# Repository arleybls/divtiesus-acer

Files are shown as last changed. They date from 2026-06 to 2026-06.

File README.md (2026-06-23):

# divtiesus-acer

A custom-PCB fork of **DivTIESUS** — a DivMMC-compatible SD/MMC card interface for the ZX Spectrum.

This fork is a **board re-layout only**: the CPLD firmware and its pinout are unchanged from
upstream, so the existing logic runs on the new PCB without modification.

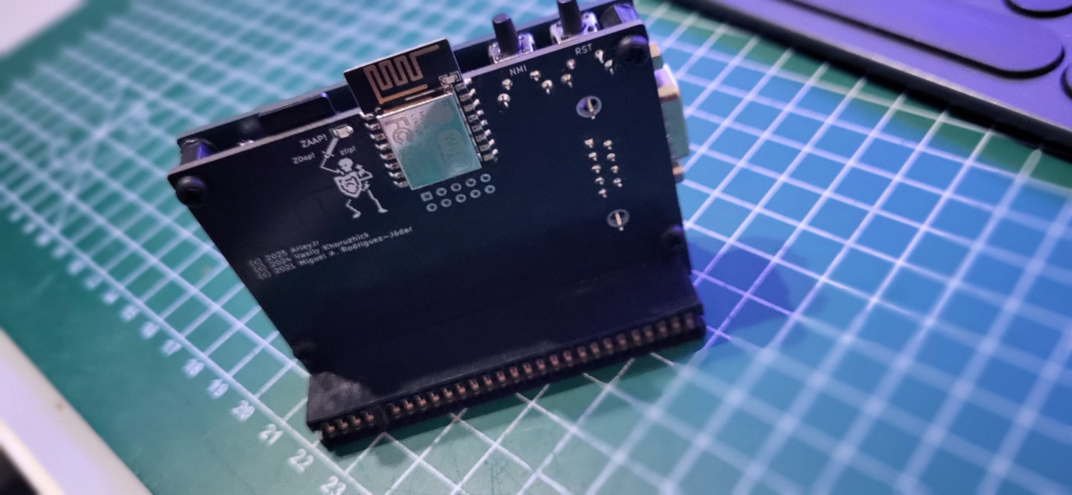
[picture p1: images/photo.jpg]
divtiesus-acer assembled board


## Lineage

| Stage | Author | Repo |
|---|---|---|
| Original DivTIESUS | Miguel Ángel Rodríguez Jodar (*mcleod-ideafix*) | https://github.com/mcleod-ideafix/divtiesus |
| KiCad redesign ("maple" edition) | anarsoul | https://github.com/anarsoul/divtiesus_maple |
| This fork (`divtiesus-acer`) | — | custom PCB re-layout based on the maple edition |

## What is unchanged from upstream

The entire `cpld/` directory matches the maple edition:

- Same Verilog sources: `tld_divtiesus.v`, `divmmc_mcleod.v`, `modo.v`, `segajoy.v`, `tres_e.v`,
  `uart.v`, `zxunoregs.v`, `zxunouart.v`
- Same `config.vh` and `Makefile`
- Same `tld_divtiesus.qsf` pin map — target device **Altera MAX II `EPM240T100C5`**

Inherited feature set:

- DivMMC-compatible interface with 8 KiB EEPROM and 128 KiB or 512 KiB RAM
- Automatic Spectrum model detection (no jumpers/switches)
- 24 MHz independent clock
- microSD card support with activity LED
- NMI and RESET buttons (file browser access)
- Optional ZX-Uno-compatible UART for WiFi (115200 baud)
- Kempston joystick interface (Atari and Sega controllers)
- Soft +3E feature removed (as in the maple edition)

## License

GPLv3, inherited from the upstream sources (see the GPL headers in `cpld/tld_divtiesus.v` and the
ZX-Uno notice in `cpld/config.vh`).

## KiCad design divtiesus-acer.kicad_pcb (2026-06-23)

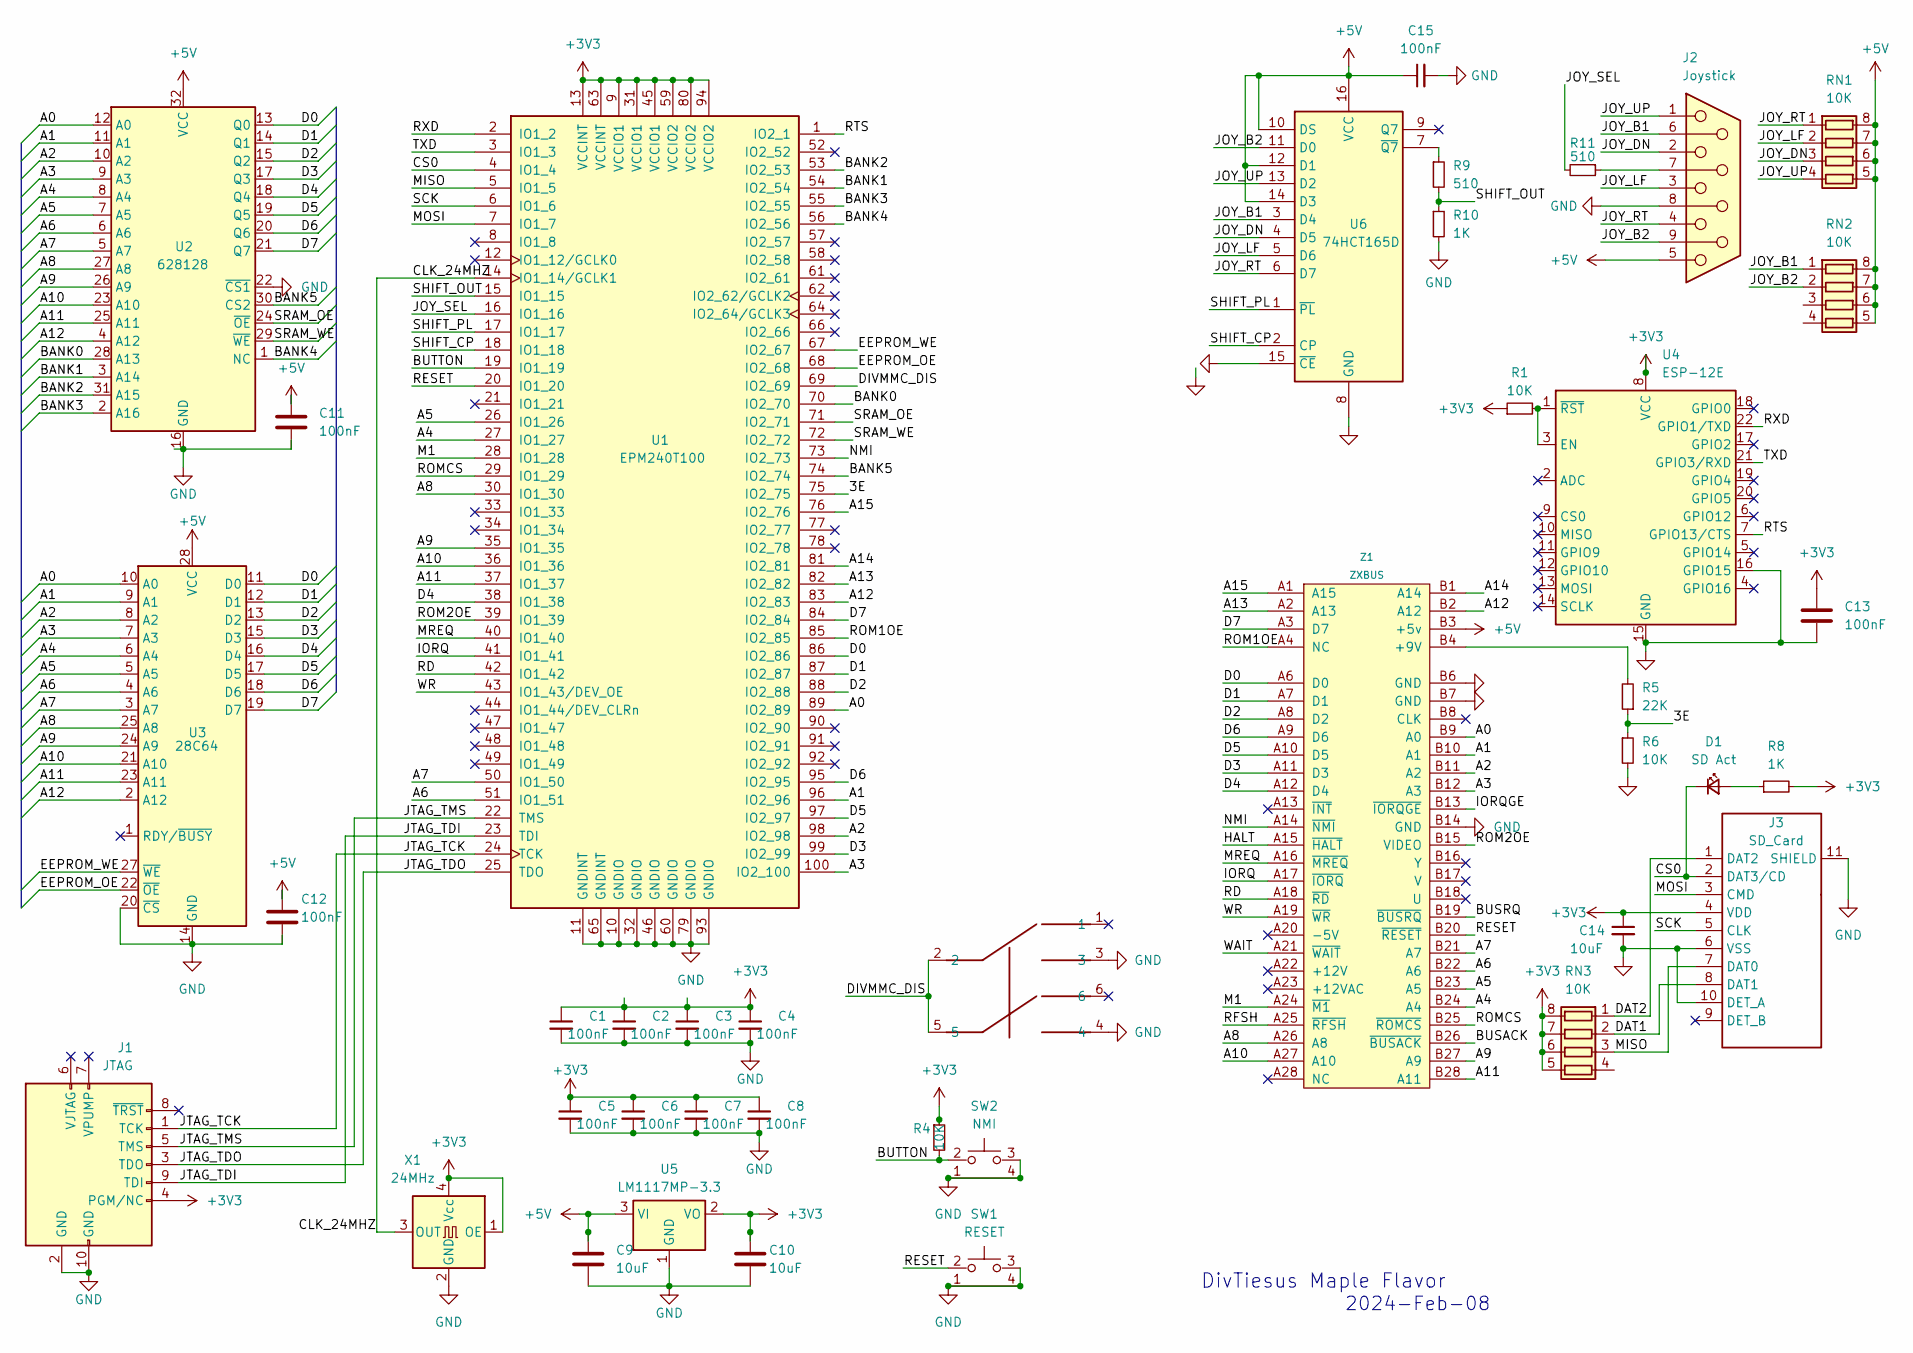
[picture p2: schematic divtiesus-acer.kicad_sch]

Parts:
C1, C2, C3, C4, C5, C6, C7, C8, C11, C12, C13, C15: 100nF; C_0603_1608Metric
C9, C10, C14: 10uF; C_0805_2012Metric
D1: SD Act; LED_0805_2012Metric
J1: JTAG; IDC-Header_2x05_P2.54mm_Vertical
J2: Joystick; DSUB-9_Male_Horizontal_P2.77x2.84mm_EdgePinOffset9.90mm_Hou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
J3: SD_Card; microSD_HC_Hirose_DM3D-SF; PARTREV AX6
JUMPER_E2: SWITCH_SMD_6PIN; SWICTH_SMD_6P
R1, R4, R6: 10K; R_0603_1608Metric
R5: 22K; R_0603_1608Metric
R8, R10: 1K; R_0603_1608Metric
R9, R11: 510; R_0603_1608Metric
RN1, RN2, RN3: 10K; R_Array_Convex_4x0603
SW1: RESET; SW_Tactile_SPST_Angled_PTS645Vx58-2LFS
SW2: NMI; SW_Tactile_SPST_Angled_PTS645Vx58-2LFS
U1: EPM240T100; TQFP-100_14x14mm_P0.5mm
U2: 628128; SSOP-32_11.305x20.495mm_P1.27mm
U3: 28C64; SOIC-28W_7.5x17.9mm_P1.27mm
U4: ESP-12E
U5: LM1117MP-3.3; SOT-223-3_TabPin2
U6: 74HCT165D; SOIC-16_3.9x9.9mm_P1.27mm
X1: 24MHz; Oscillator_SMD_SeikoEpson_SG8002CE-4Pin_3.2x2.5mm
Z1: ZXBUS; CONECTOR_SIMPLE_CARA

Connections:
+3V3: C1.1, C2.1, C3.1, C4.1, C5.1, C6.1, C7.1, C8.1, C10.1, C13.1, C14.1, J1.4 (PGM/NC), J3.4 (VDD), R1.1, R4.1, R8.2, RN3.5 (R4.2), RN3.6 (R3.2), RN3.7 (R2.2), RN3.8 (R1.2), U1.9 (VCCIO1), U1.13 (VCCINT), U1.31 (VCCIO1), U1.45 (VCCIO1), U1.59 (VCCIO2), U1.63 (VCCINT), U1.80 (VCCIO2), U1.94 (VCCIO2), U4.8 (VCC), U5.2 (VO), X1.1 (OE), X1.4 (Vcc)
+5V: C9.1, C11.1, C12.1, C15.1, J2.5, RN1.5 (R4.2), RN1.6 (R3.2), RN1.7 (R2.2), RN1.8 (R1.2), RN2.5 (R4.2), RN2.6 (R3.2), RN2.7 (R2.2), RN2.8 (R1.2), U2.32 (VCC), U3.28 (VCC), U5.3 (VI), U6.10 (DS), U6.12 (D1), U6.14 (D3), U6.16 (VCC), Z1.B3 (+5v)
/3E: R5.1, R6.1, U1.75 (IO2_75)
/A0: U1.89 (IO2_89), U2.12 (A0), U3.10 (A0), Z1.B9 (A0)
/A1: U1.96 (IO2_96), U2.11 (A1), U3.9 (A1), Z1.B10 (A1)
/A2: U1.98 (IO2_98), U2.10 (A2), U3.8 (A2), Z1.B11 (A2)
/A3: U1.100 (IO2_100), U2.9 (A3), U3.7 (A3), Z1.B12 (A3)
/A4: U1.27 (IO1_27), U2.8 (A4), U3.6 (A4), Z1.B24 (A4)
/A5: U1.26 (IO1_26), U2.7 (A5), U3.5 (A5), Z1.B23 (A5)
/A6: U1.51 (IO1_51), U2.6 (A6), U3.4 (A6), Z1.B22 (A6)
/A7: U1.50 (IO1_50), U2.5 (A7), U3.3 (A7), Z1.B21 (A7)
/A8: U1.30 (IO1_30), U2.27 (A8), U3.25 (A8), Z1.A26 (A8)
/A9: U1.35 (IO1_35), U2.26 (A9), U3.24 (A9), Z1.B27 (A9)
/A10: U1.36 (IO1_36), U2.23 (A10), U3.21 (A10), Z1.A27 (A10)
/A11: U1.37 (IO1_37), U2.25 (A11), U3.23 (A11), Z1.B28 (A11)
/A12: U1.83 (IO2_83), U2.4 (A12), U3.2 (A12), Z1.B2 (A12)
/A13: U1.82 (IO2_82), Z1.A2 (A13)
/A14: U1.81 (IO2_81), Z1.B1 (A14)
/A15: U1.76 (IO2_76), Z1.A1 (A15)
/BANK0: U1.70 (IO2_70), U2.28 (A13)
/BANK1: U1.54 (IO2_54), U2.3 (A14)
/BANK2: U1.53 (IO2_53), U2.31 (A15)
/BANK3: U1.55 (IO2_55), U2.2 (A16)
/BANK4: U1.56 (IO2_56), U2.1 (NC)
/BANK5: U1.74 (IO2_74), U2.30 (CS2)
/BUSACK: Z1.B26 (~BUSACK)
/BUSRQ: Z1.B19 (~BUSRQ)
/BUTTON: R4.2, SW2.2, U1.19 (IO1_19)
/CLK_24MHZ: U1.14 (IO1_14/GCLK1), X1.3 (OUT)
/CS0: D1.1 (K), J3.2 (DAT3/CD), U1.4 (IO1_4)
/D0: U1.86 (IO2_86), U2.13 (Q0), U3.11 (D0), Z1.A6 (D0)
/D1: U1.87 (IO2_87), U2.14 (Q1), U3.12 (D1), Z1.A7 (D1)
/D2: U1.88 (IO2_88), U2.15 (Q2), U3.13 (D2), Z1.A8 (D2)
/D3: U1.99 (IO2_99), U2.17 (Q3), U3.15 (D3), Z1.A11 (D3)
/D4: U1.38 (IO1_38), U2.18 (Q4), U3.16 (D4), Z1.A12 (D4)
/D5: U1.97 (IO2_97), U2.19 (Q5), U3.17 (D5), Z1.A10 (D5)
/D6: U1.95 (IO2_95), U2.20 (Q6), U3.18 (D6), Z1.A9 (D6)
/D7: U1.84 (IO2_84), U2.21 (Q7), U3.19 (D7), Z1.A3 (D7)
/DAT1: J3.8 (DAT1), RN3.2 (R2.1)
/DAT2: J3.1 (DAT2), RN3.1 (R1.1)
/DIVMMC_DIS: JUMPER_E2.2, JUMPER_E2.5, U1.69 (IO2_69)
/EEPROM_OE: U1.68 (IO2_68), U3.22 (~OE)
/EEPROM_WE: U1.67 (IO2_67), U3.27 (~WE)
/HALT: Z1.A15 (~HALT)
/IORQ: U1.41 (IO1_41), Z1.A17 (~IORQ)
/IORQGE: Z1.B13 (~IORQGE)
/JOY_B1: J2.6, RN2.1 (R1.1), U6.3 (D4)
/JOY_B2: J2.9, RN2.2 (R2.1), U6.11 (D0)
/JOY_DN: J2.2, RN1.3 (R3.1), U6.4 (D5)
/JOY_LF: J2.3, RN1.2 (R2.1), U6.5 (D6)
/JOY_RT: J2.4, RN1.1 (R1.1), U6.6 (D7)
/JOY_SEL: R11.2, U1.16 (IO1_16)
/JOY_UP: J2.1, RN1.4 (R4.1), U6.13 (D2)
/JTAG_TCK: J1.1 (TCK), U1.24 (TCK)
/JTAG_TDI: J1.9 (TDI), U1.23 (TDI)
/JTAG_TDO: J1.3 (TDO), U1.25 (TDO)
/JTAG_TMS: J1.5 (TMS), U1.22 (TMS)
/M1: U1.28 (IO1_28), Z1.A24 (~M1)
/MISO: J3.7 (DAT0), RN3.3 (R3.1), U1.5 (IO1_5)
/MOSI: J3.3 (CMD), U1.7 (IO1_7)
/MREQ: U1.40 (IO1_40), Z1.A16 (~MREQ)
/NMI: U1.73 (IO2_73), Z1.A14 (~NMI)
/RD: U1.42 (IO1_42), Z1.A18 (~RD)
/RESET: SW1.2, U1.20 (IO1_20), Z1.B20 (~RESET)
/RFSH: Z1.A25 (~RFSH)
/ROM1OE: U1.85 (IO2_85), Z1.A4 (NC)
/ROM2OE: U1.39 (IO1_39), Z1.B15 (VIDEO)
/ROMCS: U1.29 (IO1_29), Z1.B25 (~ROMCS)
/RTS: U1.1 (IO2_1), U4.7 (GPIO13/CTS)
/RXD: U1.2 (IO1_2), U4.22 (GPIO1/TXD)
/SCK: J3.5 (CLK), U1.6 (IO1_6)
/SHIFT_CP: U1.18 (IO1_18), U6.2 (CP)
/SHIFT_OUT: R9.2, R10.1, U1.15 (IO1_15)
/SHIFT_PL: U1.17 (IO1_17), U6.1 (~PL)
/SRAM_OE: U1.71 (IO2_71), U2.24 (~OE)
/SRAM_WE: U1.72 (IO2_72), U2.29 (~WE)
/TXD: U1.3 (IO1_3), U4.21 (GPIO3/RXD)
/WAIT: Z1.A21 (~WAIT)
/WR: U1.43 (IO1_43/DEV_OE), Z1.A19 (~WR)
GND: C1.2, C2.2, C3.2, C4.2, C5.2, C6.2, C7.2, C8.2, C9.2, C10.2, C11.2, C12.2, C13.2, C14.2, C15.2, J1.2 (GND), J1.10 (GND), J2.8, J3.6 (VSS), J3.10 (DET_A), J3.11 (SHIELD), JUMPER_E2.3, JUMPER_E2.4, R6.2, R10.2, SW1.1, SW1.3, SW1.4, SW2.1, SW2.3, SW2.4, U1.10 (GNDIO), U1.11 (GNDINT), U1.32 (GNDIO), U1.46 (GNDIO), U1.60 (GNDIO), U1.65 (GNDINT), U1.79 (GNDIO), U1.93 (GNDIO), U2.16 (GND), U2.22 (~CS1), U3.14 (GND), U3.20 (~CS), U4.15 (GND), U4.16 (GPIO15), U5.1 (GND), U6.8 (GND), U6.15 (~CE), X1.2 (GND), Z1.B6 (GND), Z1.B7 (GND), Z1.B14 (GND)
unnamed: D1.2 (A), R8.1
unnamed: J2.7, R11.1
unnamed: R1.2, U4.1 (~RST), U4.3 (EN)
unnamed: R9.1, U6.7 (~Q7)
unnamed: R5.2, Z1.B4 (+9V)

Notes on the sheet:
2024-Feb-08
DivTiesus Maple Flavor

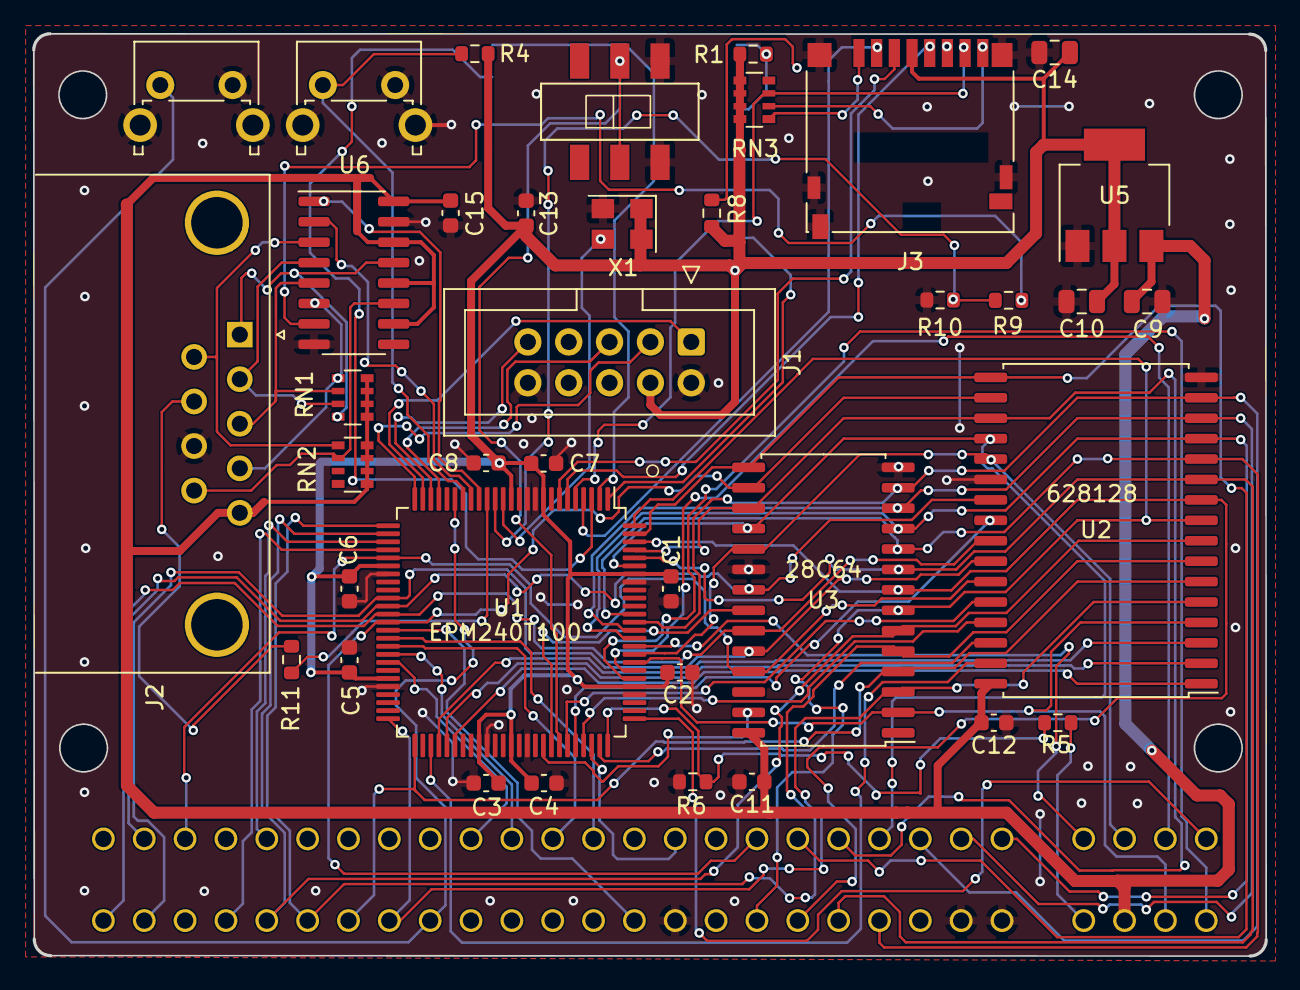
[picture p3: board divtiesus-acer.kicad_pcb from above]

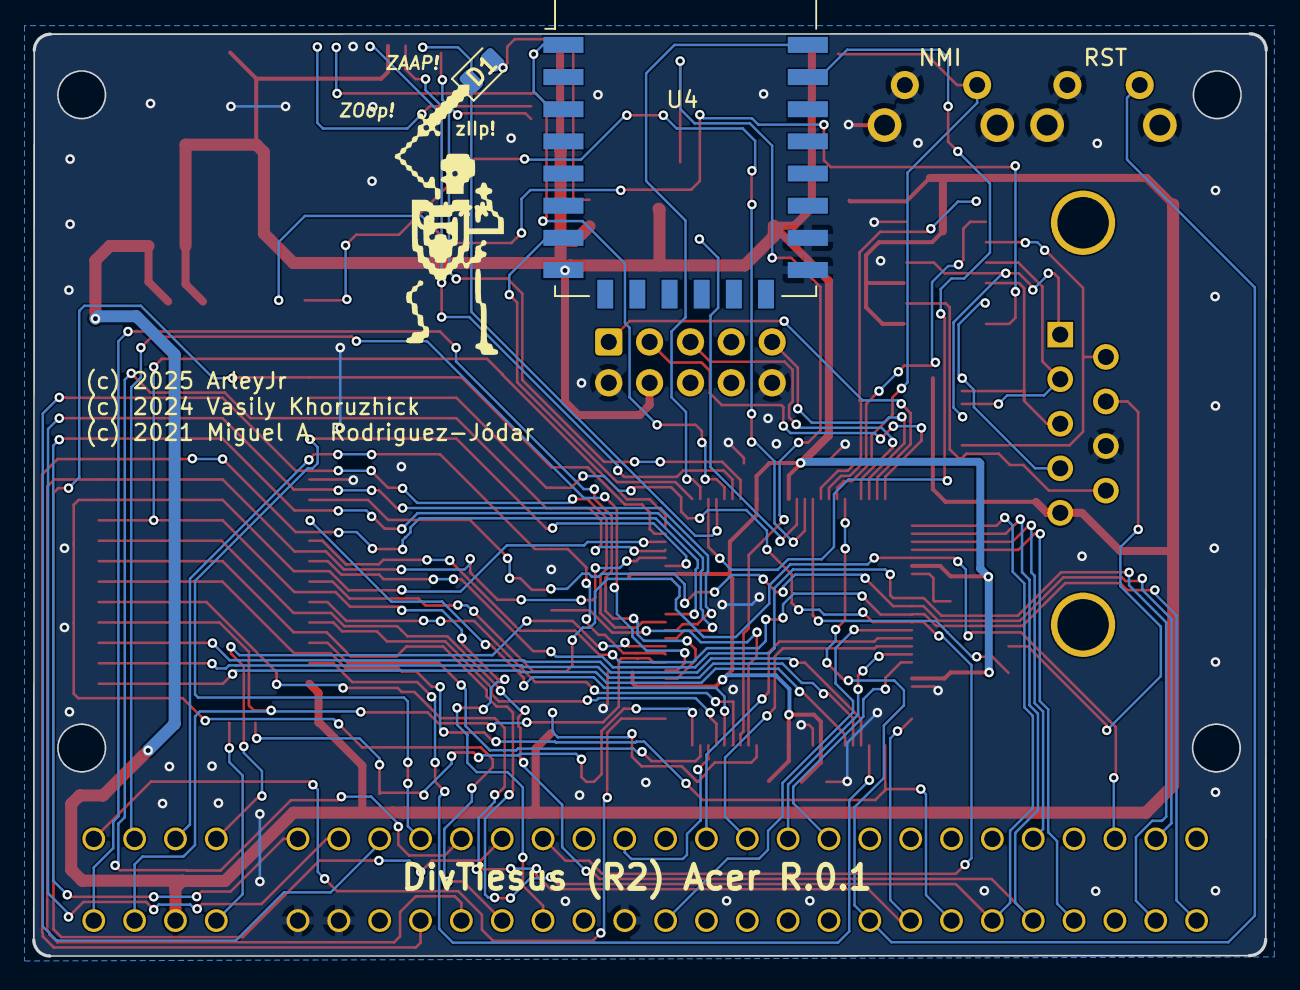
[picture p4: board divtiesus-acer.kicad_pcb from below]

Board: 2 copper layers, 76.6 x 57.4 mm, 41 parts (2 on the bottom side), 79 nets.

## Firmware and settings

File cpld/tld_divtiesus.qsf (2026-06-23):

# -------------------------------------------------------------------------- #
#
# Copyright (C) 2020  Intel Corporation. All rights reserved.
# Your use of Intel Corporation's design tools, logic functions 
# and other software and tools, and any partner logic 
# functions, and any output files from any of the foregoing 
# (including device programming or simulation files), and any 
# associated documentation or information are expressly subject 
# to the terms and conditions of the Intel Program License 
# Subscription Agreement, the Intel Quartus Prime License Agreement,
# the Intel FPGA IP License Agreement, or other applicable license
# agreement, including, without limitation, that your use is for
# the sole purpose of programming logic devices manufactured by
# Intel and sold by Intel or its authorized distributors.  Please
# refer to the applicable agreement for further details, at
# https://fpgasoftware.intel.com/eula.
#
# -------------------------------------------------------------------------- #
#
# Quartus Prime
# Version 20.1.1 Build 720 11/11/2020 SJ Lite Edition
# Date created = 11:33:43  September 21, 2021
#
# -------------------------------------------------------------------------- #
#
# Notes:
#
# 1) The default values for assignments are stored in the file:
#		tld_divtiesus_assignment_defaults.qdf
#    If this file doesn't exist, see file:
#		assignment_defaults.qdf
#
# 2) Altera recommends that you do not modify this file. This
#    file is updated automatically by the Quartus Prime software
#    and any changes you make may be lost or overwritten.
#
# -------------------------------------------------------------------------- #


set_global_assignment -name FAMILY "MAX II"
set_global_assignment -name DEVICE EPM240T100C5
set_global_assignment -name TOP_LEVEL_ENTITY tld_divtiesus
set_global_assignment -name ORIGINAL_QUARTUS_VERSION 20.1.1
set_global_assignment -name PROJECT_CREATION_TIME_DATE "11:33:43  SEPTEMBER 21, 2021"
set_global_assignment -name LAST_QUARTUS_VERSION "25.1std.0 Lite Edition"
set_global_assignment -name PROJECT_OUTPUT_DIRECTORY output_files
set_global_assignment -name MIN_CORE_JUNCTION_TEMP 0
set_global_assignment -name MAX_CORE_JUNCTION_TEMP 85
set_global_assignment -name DEVICE_FILTER_PACKAGE TQFP
set_global_assignment -name DEVICE_FILTER_PIN_COUNT 100
set_global_assignment -name ERROR_CHECK_FREQUENCY_DIVISOR "-1"
set_global_assignment -name POWER_EXT_SUPPLY_VOLTAGE_TO_REGULATOR 3.3V
set_location_assignment PIN_76 -to a[15]
set_location_assignment PIN_81 -to a[14]
set_location_assignment PIN_82 -to a[13]
set_location_assignment PIN_83 -to a[12]
set_location_assignment PIN_37 -to a[11]
set_location_assignment PIN_36 -to a[10]
set_location_assignment PIN_35 -to a[9]
set_location_assignment PIN_30 -to a[8]
set_location_assignment PIN_50 -to a[7]
set_location_assignment PIN_51 -to a[6]
set_location_assignment PIN_26 -to a[5]
set_location_assignment PIN_27 -to a[4]
set_location_assignment PIN_100 -to a[3]
set_location_assignment PIN_98 -to a[2]
set_location_assignment PIN_96 -to a[1]
set_location_assignment PIN_89 -to a[0]
set_location_assignment PIN_14 -to clk25mhz
set_location_assignment PIN_84 -to d[7]
set_location_assignment PIN_95 -to d[6]
set_location_assignment PIN_97 -to d[5]
set_location_assignment PIN_38 -to d[4]
set_location_assignment PIN_99 -to d[3]
set_location_assignment PIN_88 -to d[2]
set_location_assignment PIN_87 -to d[1]
set_location_assignment PIN_86 -to d[0]
set_location_assignment PIN_68 -to eeprom_oe_n
set_location_assignment PIN_67 -to eeprom_we_n
set_location_assignment PIN_41 -to iorq_n
set_location_assignment PIN_69 -to jumper_e
set_location_assignment PIN_28 -to m1_n
set_location_assignment PIN_5 -to miso
set_location_assignment PIN_7 -to mosi
set_location_assignment PIN_40 -to mreq_n
set_location_assignment PIN_19 -to nmi_button_n
set_location_assignment PIN_73 -to nmi_n
set_location_assignment PIN_75 -to notplus3
set_location_assignment PIN_42 -to rd_n
set_location_assignment PIN_85 -to romoe1
set_location_assignment PIN_39 -to romoe2
set_location_assignment PIN_20 -to rst_n
set_location_assignment PIN_6 -to sclk
set_location_assignment PIN_4 -to sd_cs0
set_location_assignment PIN_74 -to sram_hiaddr[5]
set_location_assignment PIN_56 -to sram_hiaddr[4]
set_location_assignment PIN_55 -to sram_hiaddr[3]
set_location_assignment PIN_53 -to sram_hiaddr[2]
set_location_assignment PIN_54 -to sram_hiaddr[1]
set_location_assignment PIN_70 -to sram_hiaddr[0]
set_location_assignment PIN_71 -to sram_oe_n
set_location_assignment PIN_72 -to sram_we_n
set_location_assignment PIN_43 -to wr_n
set_location_assignment PIN_2 -to uart_rx
set_location_assignment PIN_3 -to uart_tx
set_location_assignment PIN_1 -to uart_rts
set_location_assignment PIN_15 -to shift_q
set_location_assignment PIN_18 -to shift_cp
set_location_assignment PIN_17 -to shift_pl
set_location_assignment PIN_16 -to joy_sel
set_global_assignment -name POWER_PRESET_COOLING_SOLUTION "NO HEAT SINK WITH STILL AIR"
set_instance_assignment -name CURRENT_STRENGTH_NEW 8MA -to d[7]
set_instance_assignment -name CURRENT_STRENGTH_NEW 8MA -to d[6]
set_instance_assignment -name CURRENT_STRENGTH_NEW 8MA -to d[5]
set_instance_assignment -name CURRENT_STRENGTH_NEW 8MA -to d[4]
set_instance_assignment -name CURRENT_STRENGTH_NEW 8MA -to d[3]
set_instance_assignment -name CURRENT_STRENGTH_NEW 8MA -to d[2]
set_instance_assignment -name CURRENT_STRENGTH_NEW 8MA -to d[1]
set_instance_assignment -name CURRENT_STRENGTH_NEW 8MA -to d[0]
set_instance_assignment -name CURRENT_STRENGTH_NEW 8MA -to nmi_n
set_global_assignment -name TIMING_ANALYZER_MULTICORNER_ANALYSIS OFF
set_global_assignment -name NUM_PARALLEL_PROCESSORS ALL
set_global_assignment -name AUTO_RESTART_CONFIGURATION OFF
set_global_assignment -name ENABLE_DEVICE_WIDE_RESET OFF
set_global_assignment -name ENABLE_OCT_DONE OFF
set_global_assignment -name ENABLE_CONFIGURATION_PINS OFF
set_global_assignment -name ENABLE_BOOT_SEL_PIN OFF
set_global_assignment -name USE_CONFIGURATION_DEVICE ON
set_global_assignment -name RESERVE_ALL_UNUSED_PINS "AS INPUT TRI-STATED WITH WEAK PULL-UP"
set_global_assignment -name EXTRACT_VERILOG_STATE_MACHINES OFF
set_instance_assignment -name IO_STANDARD "3.3V SCHMITT TRIGGER INPUT" -to a[15]
set_instance_assignment -name IO_STANDARD "3.3V SCHMITT TRIGGER INPUT" -to a[14]
set_instance_assignment -name IO_STANDARD "3.3V SCHMITT TRIGGER INPUT" -to a[13]
set_instance_assignment -name IO_STANDARD "3.3V SCHMITT TRIGGER INPUT" -to a[12]
set_instance_assignment -name IO_STANDARD "3.3V SCHMITT TRIGGER INPUT" -to a[11]
set_instance_assignment -name IO_STANDARD "3.3V SCHMITT TRIGGER INPUT" -to a[10]
set_instance_assignment -name IO_STANDARD "3.3V SCHMITT TRIGGER INPUT" -to a[9]
set_instance_assignment -name IO_STANDARD "3.3V SCHMITT TRIGGER INPUT" -to a[8]
set_instance_assignment -name IO_STANDARD "3.3V SCHMITT TRIGGER INPUT" -to a[7]
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

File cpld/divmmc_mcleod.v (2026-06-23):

/*
 * This file is part of the DivTIESUS project
 * Copyright (c) 2021 Miguel Angel Rodriguez Jodar.
 * 
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
 * You should have received a copy of the GNU General Public License 
 * along with this program. If not, see <http://www.gnu.org/licenses/>.
 */

`timescale 1ns / 1ps
`default_nettype none

module divmmc_mcleod (
  // Interface with CPU
  input wire clk,
  input wire rst_n,
  input wire enable_autopage,  // jumper E = 1 (closed). = 0 (open)  
  input wire [15:0] a,
  input wire [7:0] din,
  input wire mreq_n,
  input wire iorq_n,
  input wire rd_n,
  input wire wr_n,
  input wire m1_n,
  input wire nmi_button_n,  // Button push connects to GND
  output wire nmi_to_cpu_n, // Actual NMI signal to CPU
  // Spectrum ROM shadowing
  input wire inrom48k,
  output wire [7:0] dout,
  output wire oe,
  output reg zxromcs,   // 1 to disable ZX ROM.
  // DivMMC onboard memory control
  output reg eeprom_cs,
  output reg eeprom_we_n,
  output reg sram_cs,
  output reg sram_write_n,
  output reg [5:0] sram_hiaddr,  // up to 512KB of SRAM can be addressed
  // SPI interface
  output wire sd_cs0_n,
  //output wire sd_cs1_n,
  output wire sd_sclk,
  output wire sd_mosi,
  input wire sd_miso  
  );

  localparam
    DIVMMC_CTRL = 8'hE3;

  // DIVMMC control register
  reg mapram_mode = 1'b0;
  reg conmem = 1'b0;
  reg [5:0] divmmc_sram_page = 6'b000000;
  wire iorq_wr = iorq_n | wr_n;
  always @(posedge iorq_wr or negedge rst_n) begin
    if (rst_n == 1'b0) begin
      conmem <= 1'b0;
      divmmc_sram_page <= 6'b000000;
    end
    else if (a[7:0]==DIVMMC_CTRL) begin
      conmem <= din[7];
      mapram_mode <= mapram_mode | din[6];
      divmmc_sram_page <= din[5:0];
    end
  end

  // DIVMMC automapper
  reg divmmc_is_autopaged = 1'b1;
  reg divmmc_autopage_status_after_m1 = 1'b1;
  always @(negedge mreq_n or negedge rst_n) begin
    if (rst_n == 1'b0) begin
      divmmc_is_autopaged <= 1'b1;
      divmmc_autopage_status_after_m1 <= 1'b1;
    end
    else begin
      if (m1_n == 1'b0) begin
        if (a==16'h0000 || inrom48k && (a==16'h0008 || a==16'h0038 || a==16'h0066 || a==16'h04C6 || a==16'h0562 )) begin  // Deferred automapping (maps at the next CPU clock cycle)
          divmmc_autopage_status_after_m1 <= 1'b1;
        end
        else if (a[15:8]==8'h3D && inrom48k) begin  // Non deferred automapping (Current CPU clock cycle)
          divmmc_is_autopaged <= 1'b1;
          divmmc_autopage_status_after_m1 <= 1'b1;
        end
        else if (a[15:3]==13'b0001111111111) begin  // Deferred automapping deactivation
          divmmc_autopage_status_after_m1 <= 1'b0;
        end
      end
      else
        divmmc_is_autopaged <= divmmc_autopage_status_after_m1;      
    end
  end

  // Signal NMI only when DivMMC memory is not paged. This prevents signal bouncing
  assign nmi_to_cpu_n = (nmi_button_n == 1'b0 && divmmc_is_autopaged == 1'b0)? 1'b0 : 1'b1;
  
  // EEPROM, ROMCS and SRAM control and address lines
  always @* begin
    eeprom_cs = 1'b0;
    sram_cs = 1'b0;
    sram_hiaddr = {~divmmc_sram_page[5:4],divmmc_sram_page[3:0]};
    sram_write_n = 1'b1;
    eeprom_we_n = 1'b1;

    if (conmem == 1'b1 || divmmc_is_autopaged == 1'b1 && (enable_autopage == 1'b1 || mapram_mode == 1'b1))
      zxromcs = 1'b1;
    else
      zxromcs = 1'b0;
   
    if (mreq_n == 1'b0 && a[15:14] == 2'b00 /*&& (rd_n == 1'b0 || wr_n == 1'b0)*/ ) begin
   
    //So, when CONMEM is set, there is:
    //0000-1fffh - EEPROM/EPROM/NOTHING(if empty socket), and this area is
    //	   flash-writable if EPROM jumper is open.
    //2000-3fffh - 8k bank, selected by BANK 0..1 bits, always writable.
    if (conmem == 1'b1) begin
      if (a[13] == 1'b0) begin
        if (rd_n == 1'b0) 
          eeprom_cs = 1'b1;
        if (enable_autopage == 1'b0)
          eeprom_we_n = wr_n;
      end  
      else begin
        if (rd_n == 1'b0)
          sram_cs = 1'b1;
        sram_write_n = wr_n;
        sram_hiaddr = {~divmmc_sram_page[5:4],divmmc_sram_page[3:0]};
      end
    end
    
    //When MAPRAM is set, but CONMEM is zero, and entrypoint was reached:
    //0000-1fffh - Bank No.3, read-only
    //2000-3fffh - 8k bank, selected by BANK 0..1. If it's different from Bank No.3,
    //	   it's writable.
    else if (mapram_mode == 1'b1 && conmem == 1'b0 && divmmc_is_autopaged == 1'b1) begin
      if (a[13] == 1'b0) begin
        if (rd_n == 1'b0) begin
          sram_cs = 1'b1;
          sram_hiaddr = 6'b110011;
          sram_write_n = 1'b1;
        end
      end
      else begin
        if (rd_n == 1'b0)
          sram_cs = 1'b1;
        sram_hiaddr = {~divmmc_sram_page[5:4],divmmc_sram_page[3:0]};
        if (divmmc_sram_page != 6'd3) begin
          sram_write_n = wr_n;
        end
        else begin
          sram_write_n = 1'b1;
        end
      end
    end
   
    //When MAPRAM is zero, CONMEM is zero, EPROM jumper is closed and entrypoint was
    //reached:
    //0000-1fffh - EEPROM/EPROM/NOTHING(if empty socket, so open jumper in this case),
    //	   read-only.
    //2000-3fffh - 8k bank, selected by BANK 0..1, always writable.
    else if (enable_autopage == 1'b1 && mapram_mode == 1'b0 && conmem == 1'b0 && divmmc_is_autopaged == 1'b1) begin
      if (a[13] == 1'b0) begin
        if (rd_n == 1'b0)
          eeprom_cs = 1'b1;
      end
      else begin
        if (rd_n == 1'b0)
          sram_cs = 1'b1;
        sram_write_n = wr_n;
        sram_hiaddr = {~divmmc_sram_page[5:4],divmmc_sram_page[3:0]};
      end
    end
    
    //Otherwise, there's normal speccy memory layout. No modified ROM, no shit.  
    else begin
      eeprom_cs = 1'b0;
      sram_cs = 1'b0;
      sram_write_n = 1'b1;
    end
   
    end // del IF que nos dice si estamos accediendo a los primeros 16KB
  end // del always

  sd_card_control sd (
    .clk(clk),
    .rst_n(rst_n),
    .a(a[7:0]),
    .iorq_n(iorq_n),
    .rd_n(rd_n),
    .wr_n(wr_n),
    .din(din),
    .dout(dout),
    .oe(oe),

    .sd_cs0_n(sd_cs0_n),
    //.sd_cs1_n(sd_cs1_n),
    .sd_sclk(sd_sclk),
    .sd_mosi(sd_mosi),
    .sd_miso(sd_miso)
    );

endmodule
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

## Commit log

2026-06-23 Initial commit: divtiesus-acer PCB redesign of DivTIESUS
    [divtiesus-acer-v0.1-B_Cu.gbr, divtiesus-acer-v0.1-B_Mask.gbr, divtiesus-acer-v0.1-B_Silkscreen.gbr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]
2026-06-23 Add board photo to README

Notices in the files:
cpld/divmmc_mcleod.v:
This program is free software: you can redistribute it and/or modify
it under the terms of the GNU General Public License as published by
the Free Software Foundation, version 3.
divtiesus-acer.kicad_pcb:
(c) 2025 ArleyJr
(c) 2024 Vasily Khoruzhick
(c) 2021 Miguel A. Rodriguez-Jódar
